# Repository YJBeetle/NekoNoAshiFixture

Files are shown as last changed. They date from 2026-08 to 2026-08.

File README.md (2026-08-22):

# Neko Paw Test Point and Fixture

[中文说明](README.cn.md) | English

This repository contains a "Neko Paw" Shaped Test Point design files, include KiCad Footprint and fixture design and production files.

footprint

## KiCad Footprint
In the `Local.pretty` folder, there are two type of KiCad footprint. 

 * If you don't need vias, you can use `meow.kicad_mod`. This is the one-side footprint without vias,
 * If you need double side connection or multiple layers of board, `meow_hole.kicad_mod` contains vias on the "claw tips" of neko paw, it can make your "neko paw" more beautiful with vias.

All footprints contains dowel pin on Edge Cuts.

## Fixture
This repository also contains fixtures for neko paw test point. Both of them need pogo pin to assemble.

We recommend using pogo pins with a 1.0mm needle bar diameter, and strongly advise using split-type pogo pins, such as the P50 series, as high temperatures can damage integrated pogo pins.

We highly recommend using round-tip pogo pins, because sharp-tip pogo pins may damage the appearance of the Neko Paw pads.

You also need two 1.0mm diameter * 16mm length dowel pin. 

There are two type of fixtures.

### Test Needle Fixture
Test Needle fixture is a handheld test tool. This type of fixture is good for programming a lot of chips.

You can find PCB design files in the `TestNeedle` folder.

Needle

Needle2

### Clip Fixture
Clip fixture is a good way to persistent connection to the PCB, such as debug your chip, `Clip` folder contains a FreeCAD design file `Fixture.FCStd`, you can 3D print this file with PETG or other sturdy print material. And the supplementary PCB design is also provided in the `Clip` folder.

You should use three M2 * 12mm screw to assemble this fixture, two for conbine clip and adapter PCB, one for assemble clip parts.

This type of fixture need a 0.7mm wire diameter * 7mm diameter * 20mm length spring to work with clip fixture.

Clip

Clip2

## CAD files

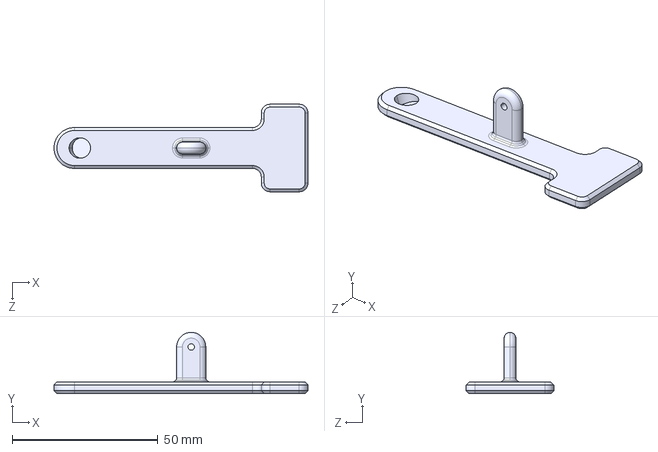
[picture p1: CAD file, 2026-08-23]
Clip/Model/JigDown.STEP
87.0 x 21.0 x 30.0 mm

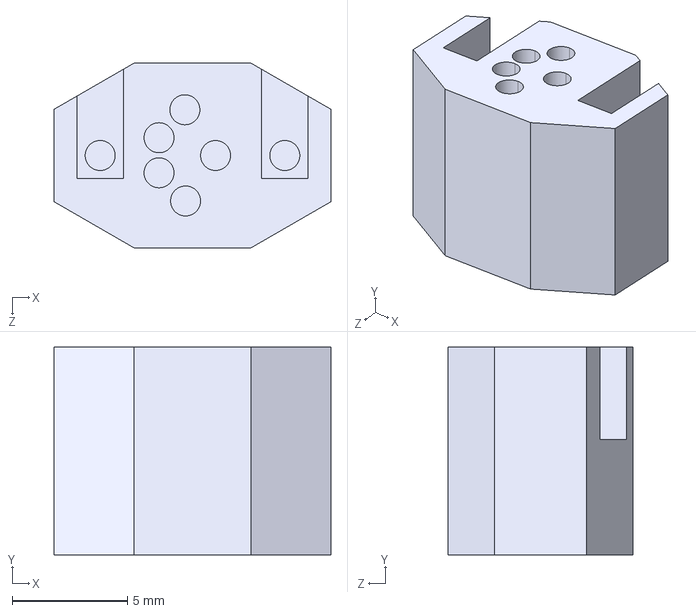
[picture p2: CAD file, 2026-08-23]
Clip/Model/InstallUtilBolck.STEP
12.0 x 9.00 x 8.00 mm

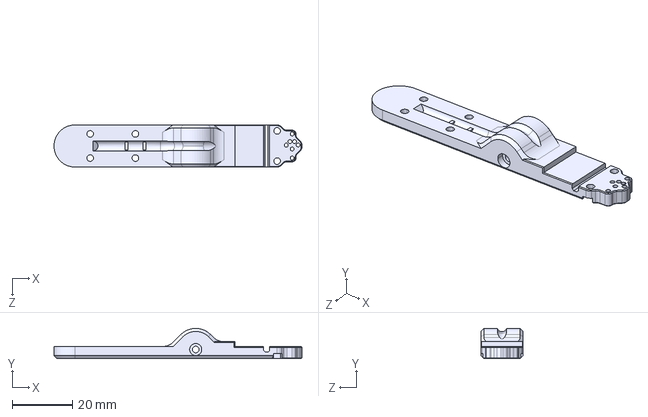
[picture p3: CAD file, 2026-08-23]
Clip/Model/JigUp.STEP
82.3 x 9.99 x 14.0 mm

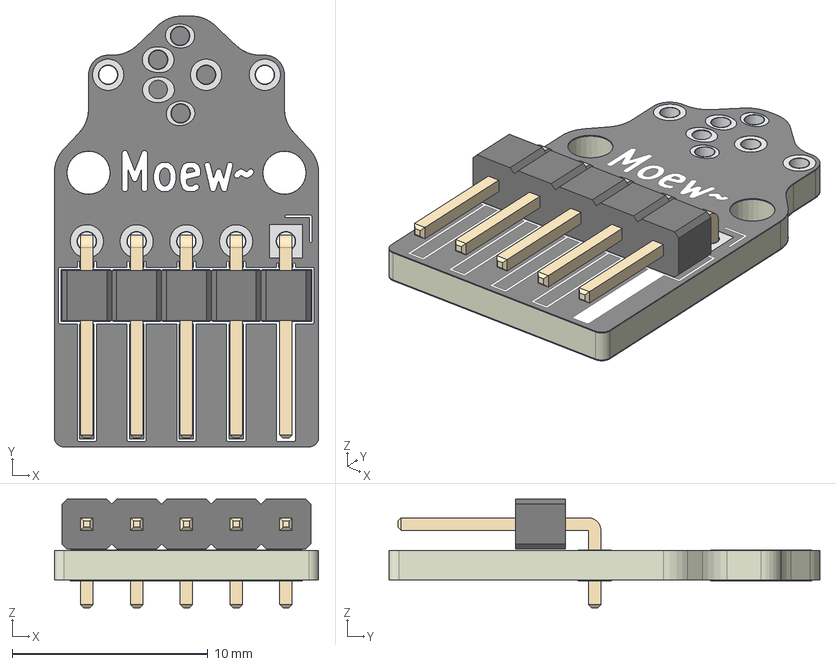
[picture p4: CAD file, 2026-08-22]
Clip/Model/ClipBoard.step
13.5 x 22.0 x 5.54 mm
PinHeader_1x05_P254mm_Horizontal
Clip-unsaved-export-5GamFX_pad
Clip-unsaved-export-5GamFX_silkscreen x 2
Clip-unsaved-export-5GamFX_soldermask x 2
Clip-unsaved-export-5GamFX_PCB

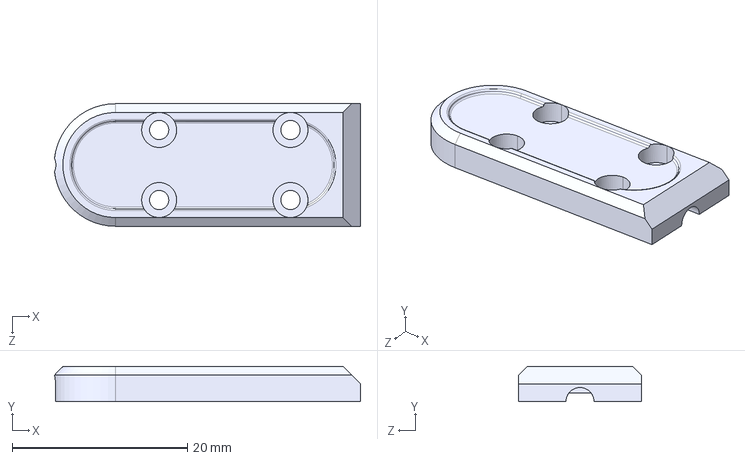
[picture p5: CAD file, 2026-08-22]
Clip/Model/LineFix.STEP
35.0 x 4.00 x 14.0 mm

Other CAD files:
UniversalModel/P50.SLDASM
Clip/Model/Jig.SLDASM
UniversalModel/P50-2S.SLDPRT
UniversalModel/P50-J1.SLDPRT
UniversalModel/P50-B1.SLDPRT
Clip/Model/Pin1x16.SLDPRT
Clip/Model/Spring0.7x7x20.SLDPRT
Clip/Model/ClipBoard.SLDPRT
Clip/Model/InstallUtilBolck.3mf
Clip/Model/InstallUtilBolck.SLDPRT
Clip/Model/JigDown.3mf
Clip/Model/JigDown.SLDPRT
Clip/Model/JigUp.3mf
Clip/Model/JigUp.SLDPRT
Clip/Model/LineFix.3mf
Clip/Model/LineFix.SLDPRT

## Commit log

2022-04-29 Add FreeCAD Clip
    [Fixture.FCStd]
2022-04-29 移动文件
2022-04-29 修改理线结构
    [Fixture.FCStd]
2022-04-29 理线结构改为在内侧
    [Fixture.FCStd]
2022-04-30 综合舒适度以及打印可行性以及出于节约材料考虑做若干修改 臂宽度改为14 圆角倒角加大 缩小前端平面
    [Fixture.FCStd]
2022-04-30 总长度缩短20mm
    [Fixture.FCStd]
2022-04-30 导入模型并且重新设计了头部 添加了定位销等
    [Fixture.FCStd]
2022-04-30 set body tip
    [Fixture.FCStd]
2022-04-30 为了兼容0.4喷头打印机 扩张0.25mm
    [Fixture.FCStd]
2022-04-30 顶部PCB后端给0.4mm的调整空间
    [Fixture.FCStd]
2022-04-30 添加了螺丝螺母的模型
    [Fixture.FCStd]
2022-04-30 统一螺丝长度 皆为M2x12 为此加厚上半部分1mm 顺便封顶 为了打印可行性 改为尖顶 加宽轴的间隙到0.4mm
    [Fixture.FCStd]
2022-04-30 离线结构的线弯曲半径过小 修改为10mm
    [Fixture.FCStd]
2022-04-30 排线的出口处下沉
    [Fixture.FCStd]
2022-04-30 减小轴间隙至0.6mm
    [Fixture.FCStd]
2022-05-01 定位销改成16mm的 定位销孔贯穿 调整若干尺寸以及开合角度 添加底板凹坑容纳定位销戳出 兼容薄板
    [Fixture.FCStd]
2022-05-06 修改了弹簧味的设计 深度从2mm改到1mm 上半部分的免支撑结构设计调整 解决弹簧在压缩后偏移的问题 改为斜的
    [Fixture.FCStd]
2022-05-06 上弹簧的内径改成4mm
    [Fixture.FCStd]
2022-05-07 弹簧翻车 买的0.8x7x15 实际测量有力度的差不多只有13mm 上下空隙9+4mm 几乎无力量 改成9+2之后卡不住 现在换成0.7x7x20 同时加深弹簧槽 倾斜角度加大至更科学 7度
    [Fixture.FCStd]
2022-05-10 添加剩下的弹簧针模型 一些模型加圆角
    [Fixture.FCStd]
2022-05-11 底板凹坑改成长条形
    [Fixture.FCStd]
2022-06-15 docs(README): add about screw
2022-06-15 docs(README): add dowel pin and spring infomation
2022-08-25 补充提交之前的设计文件
2022-09-08 改板边为非金属孔
2026-02-03 update kicad version
    [Clip.kicad_pcb, Clip.kicad_sch, Clip2.kicad_pcb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]
2026-02-03 feat: 添加 KiCad CI 工作流以生成输出文件
2026-08-21 update kicad 10 ignore
2026-08-21 docs: 添加中文 README 并更新语言链接
2026-08-22 新的分体式针模型
    [P50-2S.SLDPRT, P50-B1.SLDPRT, P50-J1.SLDPRT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]
2026-08-22 删除下电路 移动上电路
    [Clip.kicad_pcb, Clip.kicad_sch, Clip2.kicad_pcb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]
2026-08-22 更新电路板
    [Clip.kicad_pcb, Clip.kicad_sch]
2026-08-22 尺寸凑整 优化走线
    [Clip.kicad_pcb]
2026-08-22 优化封装
    [Clip.kicad_pcb]
2026-08-22 LCEDA 版本 方便免费下单
2026-08-22 阻焊颜色更新
    [Clip.kicad_pcb]
2026-08-22 移动到正确的位置
2026-08-22 圆角pin 删除多余参考
    [Jig.SLDASM, P50.SLDASM, Pin1x16.SLDPRT]
2026-08-22 优化切片
    [InstallUtilBolck.3mf]
2026-08-22 新设计棒子板
    [TestNeedle2.kicad_pcb, TestNeedle2.kicad_sch]
2026-08-22 移动文件 以及+lceda版本
    [TestNeedle.kicad_pcb, TestNeedle.kicad_sch, TestNeedle2.kicad_pcb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]
2026-08-22 头的板子
    [TestNeedle.kicad_pcb, TestNeedle.kicad_sch]
2026-08-23 优化模型以及切片
    [InstallUtilBolck.3mf, InstallUtilBolck.SLDPRT, InstallUtilBolck.STEP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]
